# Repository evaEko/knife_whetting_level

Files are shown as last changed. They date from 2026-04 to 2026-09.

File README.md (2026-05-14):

# Knife Level BLUNT

A small digital level for knife sharpening. Measures blade surface inclination in real time, displays the angle, and alerts you when you drift from your target sharpening angle.

 Built on MicroPython running on an nRF52840 microcontroller.

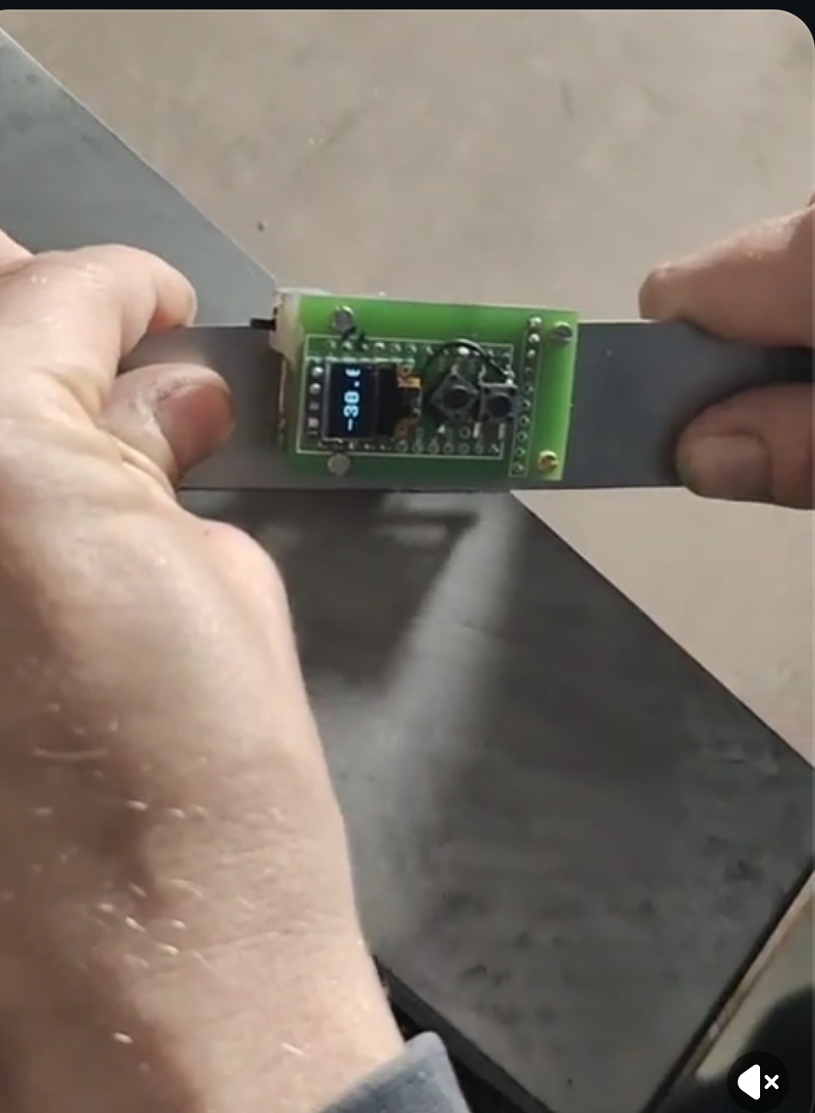
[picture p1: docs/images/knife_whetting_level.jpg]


Here are some vids:
* [demo vid of the sensor responsiveness](https://imgur.com/a/BOzFHaE).
* [demo vid of the Android app](https://i.imgur.com/QXUnDTm.mp4).
* [foolish idea with 2 displays](https://i.imgur.com/3KEsX2l.mp4)

Commercial use and resale are not permitted.

## License

- Software code, documentation, images, and hardware design files: [CC BY-NC 4.0](LICENSE)
- Third-party subcomponents may use their own license where noted (for example, `kicad/nice-nano-kicad/`)

### Third-party notices

- `kicad/nice-nano-kicad/` is a third-party nice!nano symbol/footprint library bundled with this project.
- The bundled library declares `GNU GPLv3` in `kicad/nice-nano-kicad/README.md`; keep that notice and attribution when redistributing those files.

> **Disclaimer:** This project is provided as-is, without warranty of any kind. The author is not liable for any damage, injury, or loss arising from the use, misuse, or inability to use this project or any hardware built from it.

## Getting Started

1. [Assemble the hardware](docs/HOW_TO_HARDWARE.md)
2. [Flash the firmware](docs/HOW_TO_FIRMWARE.md)
3. Optionally install the Android companion app from the `knife_level_android_apk` workflow artifact

If impatient, go over to [Quick Start](docs/QUICK_START.md).

## Known Issues

- **Android app rescan after restart** — if you power-cycle the level, the Android app will not reconnect automatically; open the app and scan again.
- **Lifted detection is experimental** — the feature that detects when the blade leaves the stone is not reliable and may produce false positives or miss lift events; treat alerts that depend on it as best-effort.

## Acknowledgements

Thanks to [jkorte-dev](https://github.com/jkorte-dev) for publishing the nRF52840 SuperMini/Nice!Nano MicroPython board definitions and UF2 builds used as a flashing base.

Development was assisted by [Claude](https://claude.ai) (Anthropic).

## Features

- **Live sharpening angle** — displays current blade surface inclination in real time on the OLED, rounded to nearest 0.5° with one decimal place
- **Rotation-invariant measurement** — the sensor attaches to the blade with a magnet and can spin freely on the blade face; the reading reports the correct blade angle regardless of how the sensor is rotated on the surface
- **Session calibration** — set the current surface as zero from the on-device settings menu or the Android app
- **Angle setting** — set the current angle as the sharpening angle
- **Visual alert** — display inverts when you drift more than the configured threshold from the target angle; both 0° and 180° orientations are treated as equivalent (knife flipped upside-down is the same angle); threshold supports decimal values (e.g. 0.5°)
- **Preset angle profiles** — define named knives and their angles in `angles.csv`; select them on-device with the top button, with optional restore of the last selected preset after reboot
- **Calibration + presets are independent** — calibrate once to set your physical reference point (zero), then switch between knife presets freely; each preset angle is always displayed relative to the calibration, never compounding
- **Bluetooth companion app** — configure display/behavior settings over BLE, calibrate from the phone, manage preset angles with CRUD operations, and back up/restore presets plus app-exposed settings after reflashing

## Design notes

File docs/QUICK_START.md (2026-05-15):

# Quick Start

Below is the simplest possible how-to.

Note: Check out the [TODO](TODO.md) file for useful info on what is probably not working. This repository is still under heavy construction.

## 1. Order the PCB

1. Install [KiCad 10](https://www.kicad.org/download/)
2. Clone this repo or download the kicad files.
2. Open [`kicad/kicad.kicad_sch`](../kicad/kicad.kicad_sch) or one of the available kicad pcb designs: run at least the design rules checker.
3. Generate Gerbers: **File → Fabrication Outputs → Gerbers**
4. Upload to a PCB manufacturer — [AISLER](https://aisler.net) is recommended (EU-based, good quality)

## 2. Buy the Components 

| Part | Notes |
|---|---|
| MCU | **nice!nano v2** (pricier, excellent build quality) or **SuperMini nRF52840** (budget option, same firmware) |
| IMU | BNO085 breakout (GY-BNO08X) |
| Display | SSD1306 0.91" OLED |
| 2× push buttons | Tactile SMD, CK KSC6xxG footprint |
| Latch switch | SPDT or SPST, for B+ power line |
| LiPo battery | 3.7V ~100mAh, smallest that fits under Pro Micro footprint (~20×30mm) |

**Battery life estimate**: with the recommended ~100mAh cell, expect about 4 to 6 hours of continuous use with the display on and BLE enabled.

**Note**: SuperMini clones sometimes need to have a resistor added to allow reading of battery voltage. It is not a showstopper but the displayed battery status will be always 0%.

## 3. Solder

1. **Display** — solder first, it will get blocked by the MCU board.
2. **BNO085 module** — next
3. **MCU** — last; make sure it sits high enough above the PCB for the battery to fit underneath. Consider using machined pin headers (sockets) so you can swap the MCU and battery without desoldering.

## 4. Flash

### 4.1. Install mpremote

**Linux:** `pip install mpremote --break-system-packages`

**macOS:** `pip3 install mpremote`

**Windows:** install [Python from python.org](https://www.python.org/downloads/) (check "Add to PATH"), then `pip install mpremote`

If `mpremote` is not found after installing on Linux/macOS, add it to your PATH:
- Linux: `echo 'export PATH=$HOME/.local/bin:$PATH' >> ~/.bashrc && source ~/.bashrc`
- macOS: `echo 'export PATH=$HOME/.local/bin:$PATH' >> ~/.zshrc && source ~/.zshrc`

### 4.2 Flash MicroPython (one-time)

1. Download the UF2 (from jkorte-dev):
   ```bash
   curl -L -o micropython-NRF52840-supermini-v1.26.1.uf2 \
     https://raw.githubusercontent.com/jkorte-dev/micropython-board-NRF52840/main/firmware/micropython-NRF52840-supermini-v1.26.1.uf2
   ```
2. Connect the MCU with a data USB cable to your computer.
3. Short the **RST** and **GND** pins twice in quick succession — the board mounts as a drive called `NICENANO`
4. Copy the firmware to the bootloader drive:

   **Linux:** `cp micropython-NRF52840-supermini-v1.26.1.uf2 /run/media/$USER/NICENANO/`

   **macOS:** `cp micropython-NRF52840-supermini-v1.26.1.uf2 /Volumes/NICENANO/`

   **Windows:** drag and drop the `.uf2` file onto the `NICENANO` drive in Explorer.

   The drive unmounts automatically.

### 4.3 Flash the firmware

1. Go to the [latest workflow run](https://github.com/evaEko/knife_whetting_level/actions/workflows/build.yml) and download the `knife_level_firmware` artifact. Extract the zip.
2. Go to the extracted folder.
2. Edit `src/angles.csv` or `src/config.txt` before flashing. See [HOW_TO_FIRMWARE.md](HOW_TO_FIRMWARE.md) for details.
5. Run from the folder with extract firmware:

```bash
python flash.py
```

Select your port from the menu when prompted. The script will flash all files and reset the board.

### Android app (optional)

Go to the same [workflow run page](https://github.com/evaEko/knife_whetting_level/actions/workflows/build.yml) and download the `knife_level_android_apk` artifact.

1. Extract the artifact zip on your Android device or computer
2. Copy `app-debug.apk` to your phone if needed
3. Open the APK on the phone and allow installation from unknown sources if Android asks
4. Install the app

**Compatibility**

- Android only
- The app connects directly to the device over BLE; no account, pairing, or cloud service is involved

**Known issues**

- If the MCU is not in measurement mode, the app may stay connected but live angle updates pause until the MCU returns to measuring
- BLE reconnect behavior can vary by phone vendor and Android version; if discovery fails after a disconnect, wait a moment and try again
- The app is distributed as an APK artifact, not through Google Play, so Android may show the standard warning about installing from unknown sources

## 5. Use

**Power on** — battery percentage shows for 1.5 s, then the live pitch angle appears.

### Step 1 — Calibrate

Calibration records the full 3D orientation of the sensor placed flat on the stone. This is the zero reference — all angle readings are relative to the stone surface regardless of how the sensor is mounted or rotated.

Do this at the start of every session, after you have positioned your stone. Redo it whenever the stone moves.

1. Place the device flat on your stone.
2. Short-press the low button to open **Settings**.
3. On **Calibration**, short-press the low button.
4. Short-press the low button again — after a settle delay the reading is saved and the device returns to measurement

The display now shows angles relative to your stone surface.

### Step 2 — Set an angle (optional)

> You can sharpen using the live angle display without setting any target. Setting an angle adds deviation detection with alert: the display inverts when you drift more than the configured deviation threshold (configurable), giving you a visual alert.

Short-press the top button to open the preset menu. Cycle through options with the top button, confirm with the low button.

**To use a preset knife angle** — cycle to the knife name and press low.

**To set a custom angle** - cycle to **Custom** and press low.

**To clear the target** — cycle to **Clear** in the preset menu and press low.

## 6. Charging

> **Important (known limitation):** while charging over USB, the latch power switch must be in the ON position. If the latch switch is OFF, the battery will not charge.

With the recommended ~100mAh battery, a full charge is usually enough for one sharpening session. 

## 8. Reflashing

When you want to update the firmware:

1. Connect to computer.
2. **Short-press both buttons at the same time** — the display shows "Ready to flash..."
   - **Note:** once flash mode is active, the only way out is to reset (short RST to GND) or power off/on.
3. If you are flashing from the downloaded firmware package, run `python flash.py`
4. If you are flashing from this repository checkout, run `python build_flash.py`

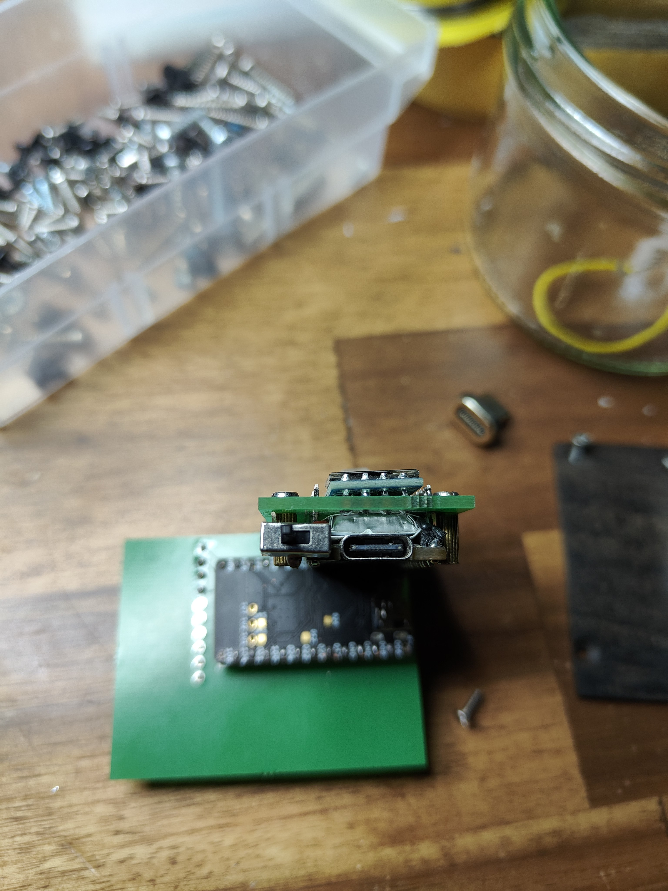
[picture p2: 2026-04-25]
docs/images/pcb_ready/ready_front.jpg

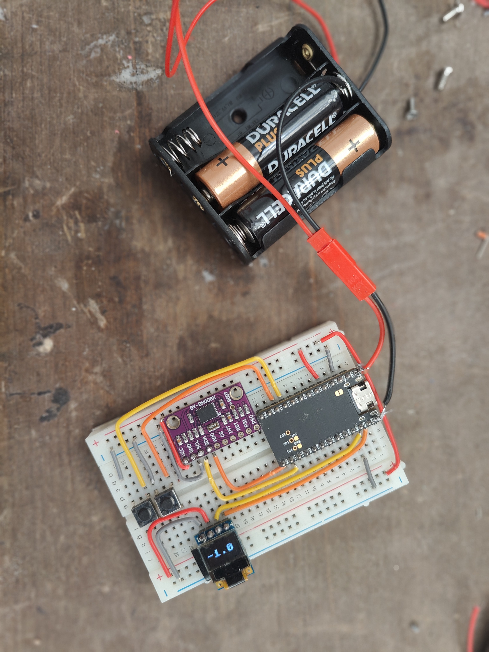
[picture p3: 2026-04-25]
docs/images/breadboard/breadboard_bat.jpg

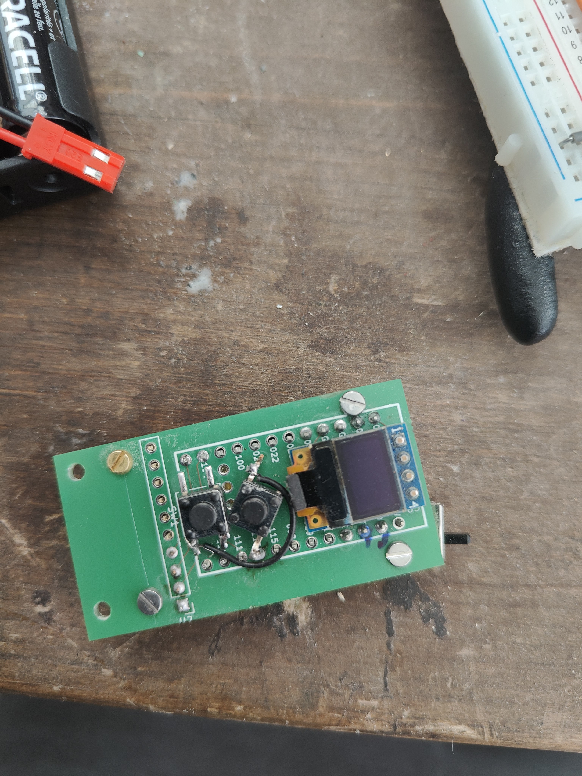
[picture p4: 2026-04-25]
docs/images/pcb_ready/ready_top.jpg

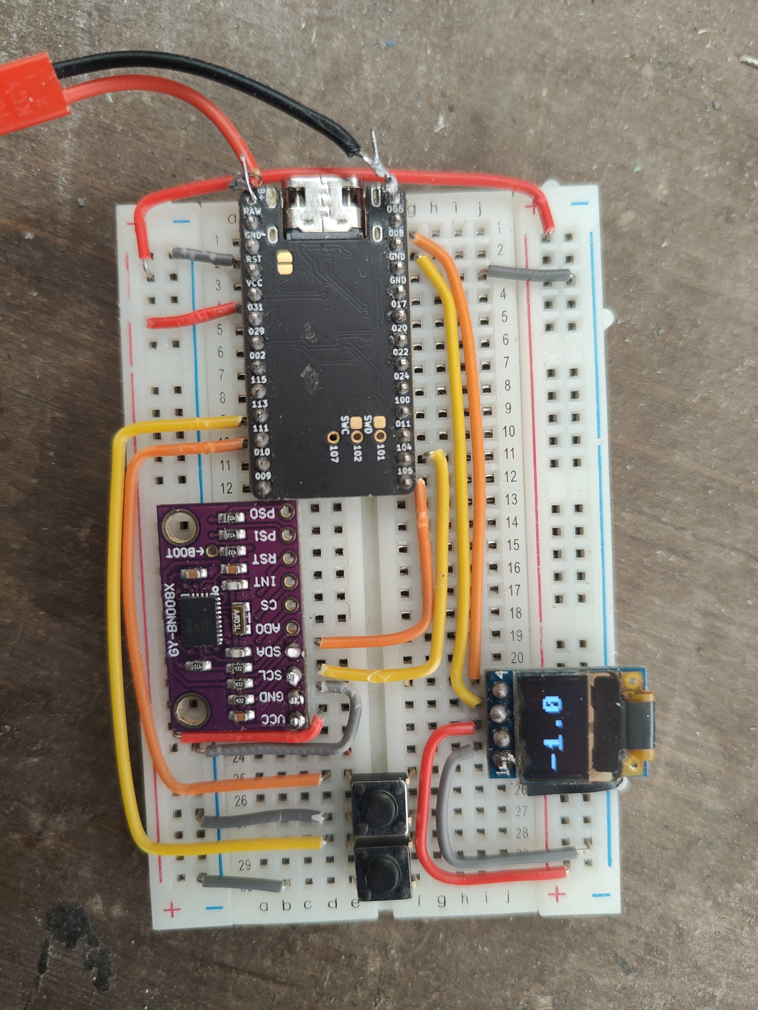
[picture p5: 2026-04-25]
docs/images/breadboard/breadboard.jpg

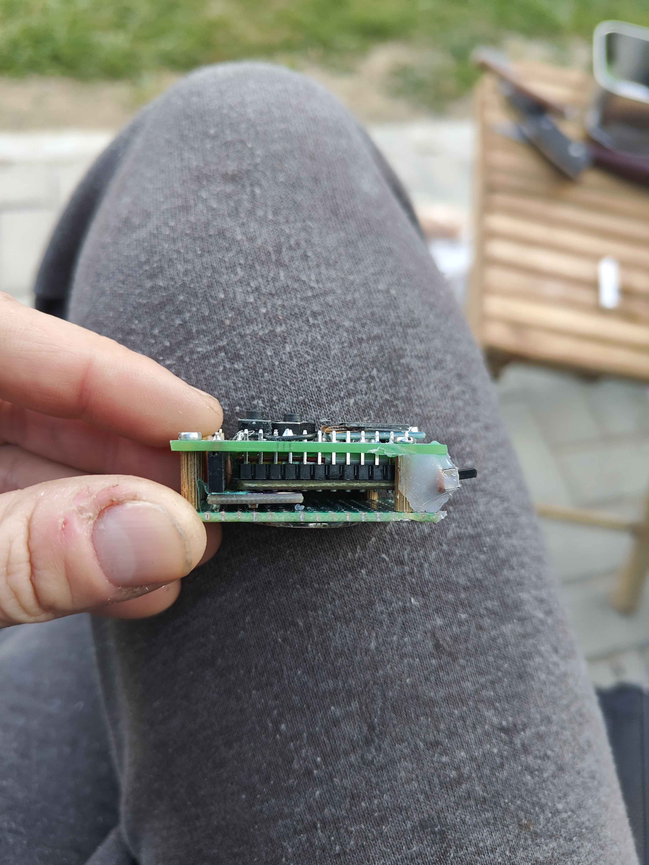
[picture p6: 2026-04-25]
docs/images/pcb_ready/ready_side.jpg

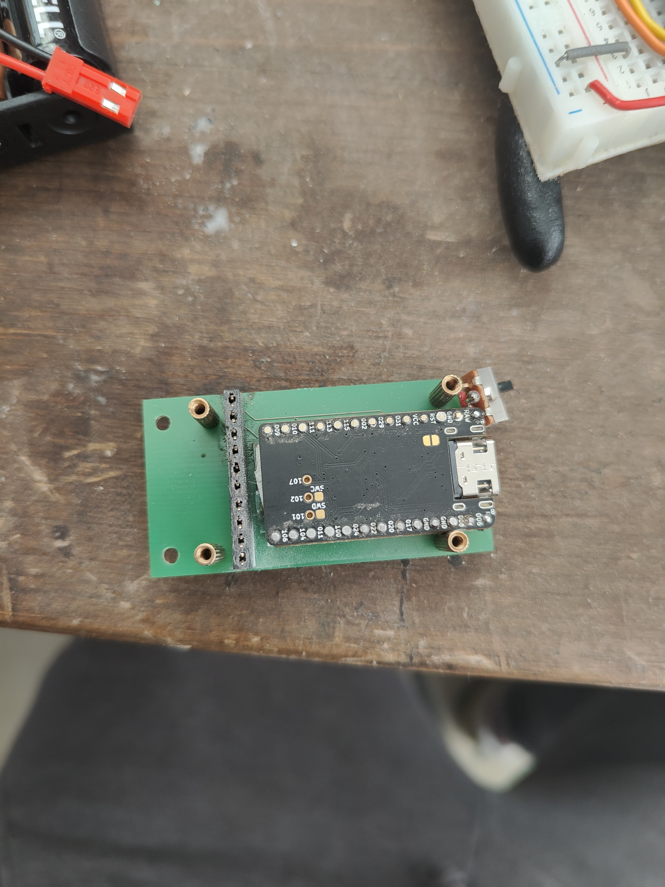
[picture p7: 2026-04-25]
docs/images/pcb_ready/ready_bottom.jpg

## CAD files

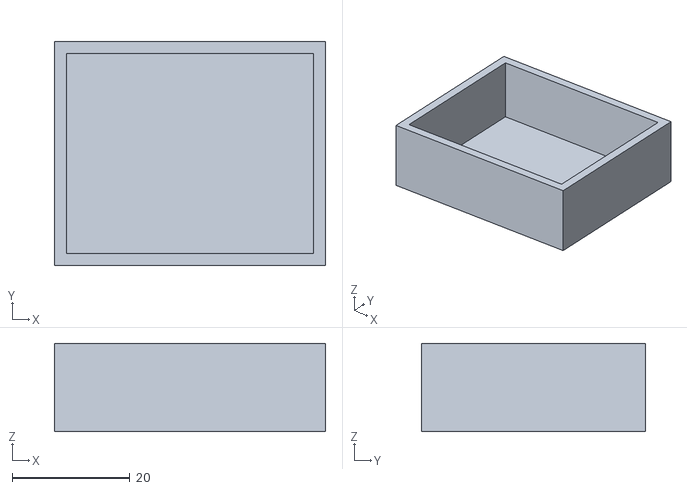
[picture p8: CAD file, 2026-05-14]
case/device_housing.stl
46.0 x 38.0 x 15.0

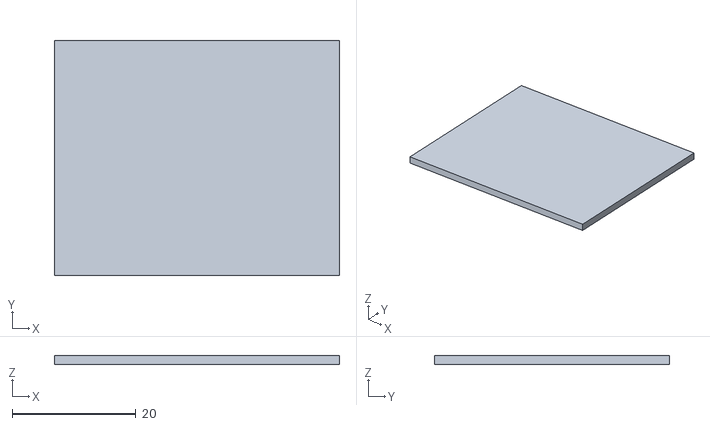
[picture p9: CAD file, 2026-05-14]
case/device_lid.stl
46.0 x 38.0 x 1.50

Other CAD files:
case/case.blend

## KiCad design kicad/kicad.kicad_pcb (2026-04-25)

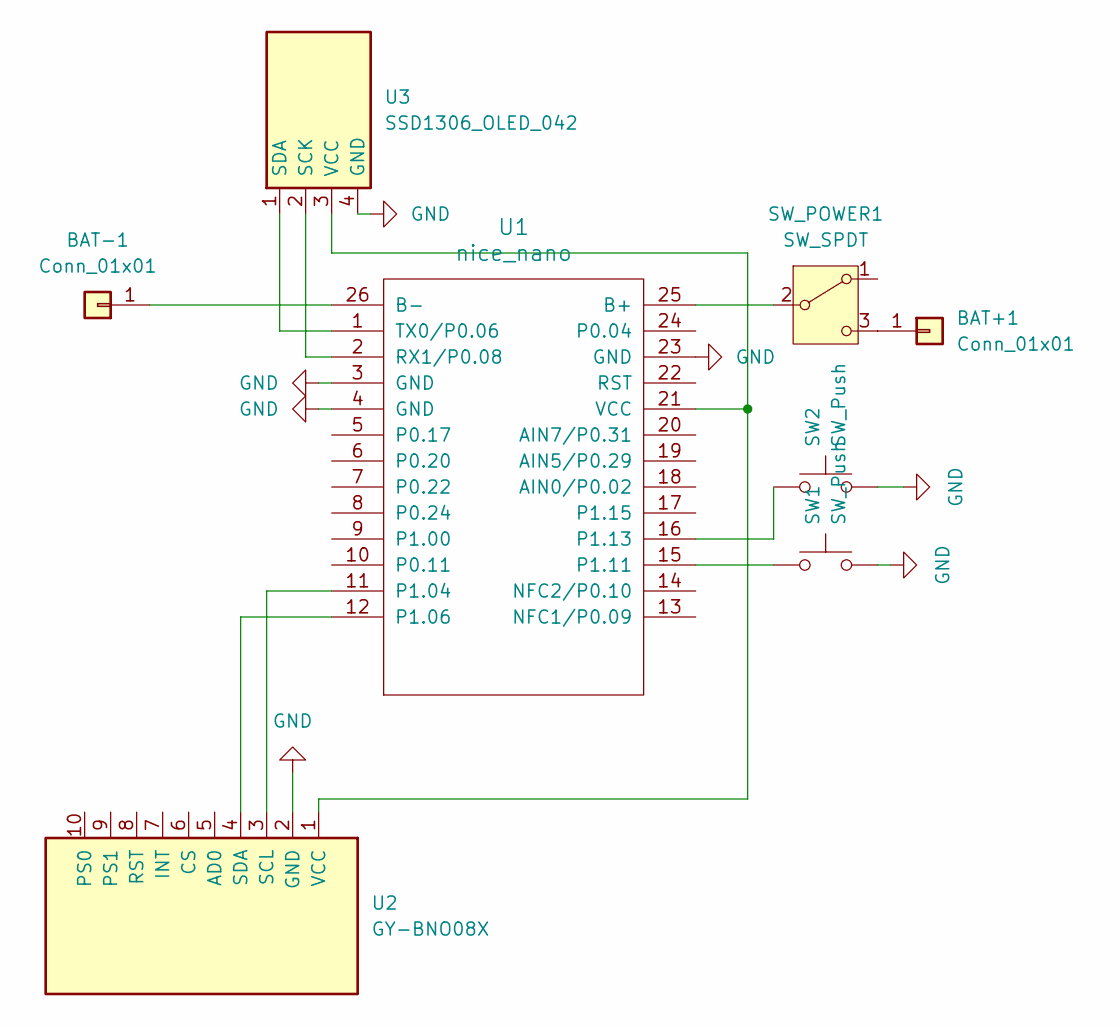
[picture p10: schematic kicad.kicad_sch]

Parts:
BAT+1: Conn_01x01; SolderWire-0.1sqmm_1x01_D0.4mm_OD1mm
BAT-1: Conn_01x01; SolderWire-0.1sqmm_1x01_D0.4mm_OD1mm
SW1, SW2: SW_Push; SW_Push_1P1T_NO_CK_KSC6xxG
SW_POWER1: SW_SPDT; SW_SPDT_Shouhan_MSK12C02
U1: nice_nano; nice_nano_with_bat_pins
U2: GY-BNO08X; PinHeader_1x10_P2.54mm_Vertical
U3: SSD1306_OLED_042; PinHeader_1x04_P2.54mm_Vertical

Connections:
GND: SW1.2, SW2.2, U1.3 (GND), U1.4 (GND), U1.23 (GND), U2.2 (GND), U3.4 (GND)
unnamed: BAT+1.1, SW_POWER1.3 (C)
unnamed: BAT-1.1, U1.26 (B-)
unnamed: SW_POWER1.2 (B), U1.25 (B+)
unnamed: U1.11 (P1.04), U2.3 (SCL)
unnamed: U1.12 (P1.06), U2.4 (SDA)
unnamed: SW1.1, U1.15 (P1.11)
unnamed: SW2.1, U1.16 (P1.13)
unnamed: U1.2 (RX1/P0.08), U3.2 (SCK)
unnamed: U1.1 (TX0/P0.06), U3.1 (SDA)
unnamed: U1.21 (VCC), U2.1 (VCC), U3.3 (VCC)

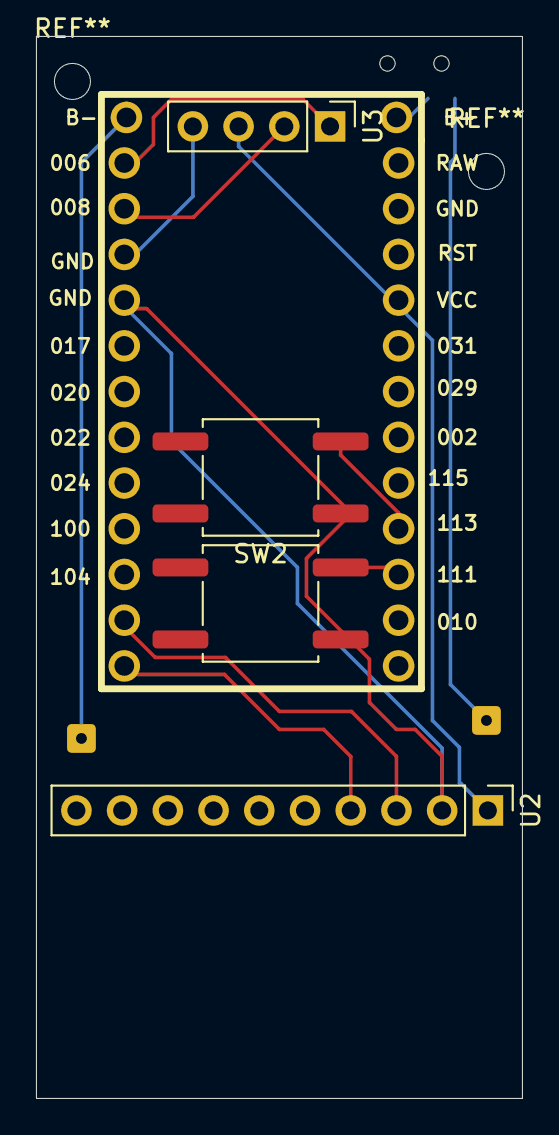
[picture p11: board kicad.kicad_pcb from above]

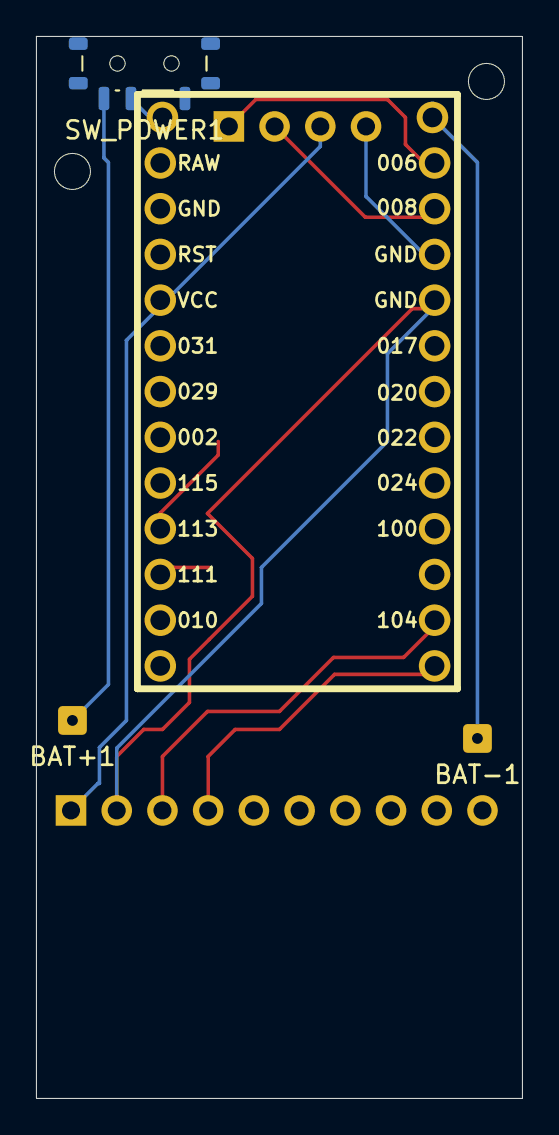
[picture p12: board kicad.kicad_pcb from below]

Board: 2 copper layers, 27.0 x 59.0 mm, 8 parts (3 on the bottom side), 11 nets.

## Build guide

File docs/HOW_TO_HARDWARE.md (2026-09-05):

# Hardware Assembly

The KiCad schematic is in [`kicad/kicad.kicad_sch`](../kicad/kicad.kicad_sch). Open it in KiCad 10 to view the full schematic and generate gerbers for PCB fabrication. Have it fabricated. 

It is possible to do this on perfboard: it is a good idea to breadboard it first and plan the perfboard version, use both sides (TODO: documentation of perfboard options).

If you have the PCB, solder in this order: display first, then the BNO085 module, then the MCU. Leave enough clearance under the MCU for the battery. Connect the battery wires to B+ and B- directly on the MCU board.

Consider socketing the MCU using mill-max or machined pin headers instead of soldering it directly. This lets you swap or replace the board without desoldering.

Refer to the images on [breadboarding](images/breadboard/)
and on [PCB assembly](images/pcb_assembly/)

After assembly, [flash the firmware](HOW_TO_FIRMWARE.md)

## Bill of Materials

| Component | Part | Notes |
|---|---|---|
| Microcontroller | **nice!nano** or nRF52840 pro-micro compatible board | nRF52840-based, chosen for built-in LiPo charging — no separate charging module needed |
| IMU | BNO085 | I2C, addr `0x4B` |
| Display | 0.42" OLED (SSD1306) | I2C, 72×40 px, addr `0x3C` |
| Two push buttons  | Tactile push button | SMD, e.g. CK KSC6xxG footprint |
| Battery | LiPo 3.7V 100mAh | Smallest single-cell LiPo that fits under the Pro Micro footprint (e.g. 20×30mm) |
| PCB| Custom PCB (see kicad folder) | The PCB makes everything simpler, however, you can perfboard it: you will need to use both sides: plan ahead. |

## Note on MCU Board

The following boards have been tested and confirmed working:

- **nice!nano v1.0** — works
- **nice!nano v2.0** — works (recommended; has the most reliable charging circuit)
- **SuperMini nRF52840** — works; cheaper alternative, pin-compatible with nice!nano

All three use the nRF52840 and support the same MicroPython firmware. Choose any of them — the firmware runs identically on all.

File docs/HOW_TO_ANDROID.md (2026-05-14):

# HOW TO: Blunt Android App

## What is the Blunt Android App?
The Blunt Android app is a companion application for the Knife Level device. It allows you to connect to your level via Bluetooth, view measurements, set target angles, and customize alerts. The app is not required for using the Knife Level — it is provided purely for convenience and enhanced user experience.

### Settings available from the app

The settings screen has two tabs: **Application** (stored on the phone) and **Level** (sent to the device over BLE).

#### Application tab

**Lifted**
- **Enable** — detect when the blade leaves the stone and pause deviation alerts
- **Velocity threshold (°/s)** — minimum angular speed that triggers a lift event (3–30°/s); lower = more sensitive
- **Debounce (ms)** — how long to wait after the last movement before returning to on-stone state (200–4000 ms); higher = fewer false detections when holding the blade in the air

**Measurement Data**
- **Angle Format** — `2d` (two decimals), `1d` (one decimal), `0.5` (nearest 0.5°)
- **Target Name** — show the preset name (e.g. Gyuto) above the live angle
- **Target Angle** — show the target angle value below the live reading
- **Deviation Range** — show the allowed angle range (e.g. 13.0°–17.0°) based on target and threshold
- **Delta** — show the signed difference between the live angle and the target (e.g. Δ+1.2°)

**Visual Alert**
- **Direction Arrows** — show ↑↓ arrows indicating which way to correct the blade; the active arrow turns the alert colour when outside the threshold
- **Arrow Size** — Small / Medium / Large / XL (shown when Direction Arrows is on)
- **Background Color** — change the background colour when outside the deviation threshold
- **Angle too high / too low colour** — pick from Red, Orange, Pink, Teal, Blue (shown when Background Color is on)

**Sound Alert**
- **On angle too high** — play a tone when the blade is above target + threshold; tone pitch and optional custom audio file are configurable
- **On angle too low** — play a tone when the blade is below target − threshold; tone pitch and optional custom audio file are configurable
- **On target** — play a custom audio file (looped) when the blade is within the target range; resumes from where it was interrupted
  - **Continue on lifted** — keep the on-target audio playing when the blade is lifted off the stone

**Custom Angle**
- **Measurement delay (s)** — countdown before the live angle is captured as a custom target (1–15 s); gives time to position the blade

#### Level tab

These settings are written to the device over BLE. Press **Apply** to send.

- **Deviation Threshold (°)** — how far from the target angle before the display inverts (0.0°–4.0°)
- **Capture delay (s)** — settle time before the surface normal is sampled during calibration (1–30 s)

## Installation
You have two options to install the app on your Android phone:

### Option 1: Download APK from Workflow
1. Go to the GitHub repository's Actions tab.
2. Find the latest successful build workflow run.
3. Download the APK artifact to your phone or computer.
4. Transfer the APK to your phone if needed.
5. On your phone, open the APK file and follow the prompts to install. You may need to allow installation from unknown sources.

### Option 2: Build and Install Yourself
1. Install Android Studio (https://developer.android.com/studio) and required SDKs.
2. Clone the repository to your computer.
3. Open the `App` project in Android Studio.
4. Connect your Android phone via USB and enable USB debugging.
5. Click "Run" in Android Studio to build and install the app directly to your device.

## Uploading and Running the App
- After installation, locate the Blunt app icon on your phone and open it.
- Grant all requested permissions (Bluetooth, Location) for proper operation.
- The app will scan for your Knife Level device. Select it to connect.

## Troubleshooting
- **I cannot see my level during scanning:**
  - Make sure BLE is enabled on your Knife Level device.
  - Check if the device appears in your phone's Bluetooth device list. If not, turn the level off and on again.
- **I can't see details about my target angle:**
  - Ensure you have selected a preset or set a custom angle in the app.
- **I don't want some of the alerts:**
  - Go to the app's settings and customize or disable alerts as desired.

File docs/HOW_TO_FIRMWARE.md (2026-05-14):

# How To

## Setup

### Install Python

Make sure Python 3 is installed:

```bash
python --version
```

Python 3.10+ is recommended.

### Install git

**Linux (Debian/Ubuntu):**
```bash
sudo apt install git
```

**Linux (Fedora):**
```bash
sudo dnf install git
```

**macOS:**
```bash
brew install git
```

**Windows:** Download from [git-scm.com](https://git-scm.com/download/win) and run the installer.

### Flash MicroPython (one-time)

MicroPython must be flashed to the board before deploying any code. Download the UF2 from the upstream board-definition repository.

1. **Enter bootloader** — double-tap the reset button on the board. A drive called `NICENANO` will mount.
2. **Download UF2**:
   ```bash
   curl -L -o micropython-NRF52840-supermini-v1.26.1.uf2 \
     https://raw.githubusercontent.com/jkorte-dev/micropython-board-NRF52840/main/firmware/micropython-NRF52840-supermini-v1.26.1.uf2
   ```
3. **Flash**:

   **Linux:**
   ```bash
   cp micropython-NRF52840-supermini-v1.26.1.uf2 /run/media/$USER/NICENANO/
   ```
   **macOS:**
   ```bash
   cp micropython-NRF52840-supermini-v1.26.1.uf2 /Volumes/NICENANO/
   ```
   **Windows:** drag and drop the `.uf2` file onto the `NICENANO` drive in Explorer.

   The board reboots automatically when the copy completes.
4. **Verify** — the `NICENANO` drive disappears and a serial port appears (`/dev/ttyACM0` on Linux, `/dev/tty.usbmodem*` on macOS, `COM*` on Windows).

### Downloading release artifacts

If you do not want to build from the repository manually, open the [Build artifacts workflow](https://github.com/evaEko/knife_whetting_level/actions/workflows/build.yml) and download:

- `knife_level_firmware` for the packaged firmware bundle
- `knife_level_android_apk` for the Android companion app APK

### Install mpremote

**Linux:**
```bash
pip install mpremote --break-system-packages
```
If `mpremote` is not found after installing, add `~/.local/bin` to your PATH:
```bash
echo 'export PATH=$HOME/.local/bin:$PATH' >> ~/.bashrc && source ~/.bashrc
```

**macOS:**
```bash
pip3 install mpremote
```
If `mpremote` is not found, add it to your PATH:
```bash
echo 'export PATH=$HOME/.local/bin:$PATH' >> ~/.zshrc && source ~/.zshrc
```

**Windows:** install [Python from python.org](https://www.python.org/downloads/) (check "Add to PATH" during install), then:
```
pip install mpremote
```

---

## Flashing

### Prepare sources

Clone the repository:

```bash
git clone https://github.com/evaEko/knife_whetting_level.git
cd knife_whetting_level
```

Edit [`src/config.txt`](../src/config.txt) to set your pin assignments, deviation threshold, and capture delay before flashing. The file is a simple `key=value` text file — each line is self-explanatory.

You can also edit [`src/angles.csv`](../src/angles.csv) before flashing if you want to ship a default preset list in the firmware image.

### Connecting the MCU

Plug in the device and find the assigned serial port:

**Linux:** run `dmesg -w` before plugging in and look for a line like:
```
cdc_acm 3-2:1.0: ttyACM0: USB ACM device
```
The port will be `/dev/ttyACM0` or similar.

**macOS:** run `ls /dev/tty.usbmodem*` after plugging in. The port will be something like `/dev/tty.usbmodem1101`.

**Windows:** open Device Manager → Ports (COM & LPT) — the device will appear as `USB Serial Device (COM3)` or similar.

### Getting the device ready to flash

mpremote needs the device to be at the MicroPython REPL prompt before it can transfer files. There are two ways to get there:

Short-press both buttons simultaneously

Press both buttons at the same time (short press). The display will show "Ready to flash..." and the device drops to REPL.

Note: once flash mode is active, the only way out is to reset (short RST to GND) or power-cycle the device.

### Flash automatically

Run from the `knife_level_python` directory:

```bash
python build_flash.py
```

You can also pass the serial port explicitly, for example:

```bash
python build_flash.py /dev/ttyACM0
```

The script auto-discovers all files under `src/` (excluding `src/tools/`) and flashes them in one go. `angles.csv` is also flashed automatically.

### REPL access

```bash
mpremote connect /dev/ttyACM0 repl
```

Hit **Ctrl+C** to interrupt `main.py` and get the `>>>` prompt.

## Runtime controls

- Short-press low: open settings menu (`Calibration`, `BLE`, `Deviation`, `Exit`)
- Short-press top (when calibrated): open preset-angle selection menu
- Short-press top (when uncalibrated): go directly to calibration capture
- Short-press both buttons: enter flash mode

### Settings menu

| Item | Behaviour |
|---|---|
| Calibration | Capture stone surface normal; top=cancel, low=capture |
| BLE | Toggle BLE on/off (top), back to menu (low) |
| Deviation | Adjust deviation threshold; top=+0.1°, long-top=+0.5°, low=save, long-low=cancel |
| Exit | Return to measurement |

### Preset-angle selection menu

Cycle through presets with top, confirm with low. Special items at the end:

| Item | Behaviour |
|---|---|
| Custom | Capture the current blade angle as target; top=cancel, low=capture |
| Clear | Unset the current target angle and return to measurement |
| Exit | Return to measurement without changing target |

### Android companion app

Install it from the `knife_level_android_apk` workflow artifact. Refer to [Android app how-to](HOW_TO_ANDROID.md)

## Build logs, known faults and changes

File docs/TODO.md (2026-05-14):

# TODO

# Case

work in progress

# Firmware

* implement correct detection of battery connected when on usb cable
* refactor ble protocol and related
* fix battery status reading

# Known Issues

- Battery readings can be erratic.
- Occasionally, the Android app cannot detect the level; if this happens, turn the level device off and on again, enable bluetooth and in your Android app rescan.

## GitHub

## PCB

- tidy up: currently multiple versions: the default one, one with sensor on the side, one with sensor on the size and with a larger display (driver needed), 

## Angle Format Setting

## Measurement Improvements

### On-Stone Detection *(needs improvement)*
Basic implementation in place: pitch-based threshold (12°) with 800 ms debounce
on return. Known limitations:
- Threshold is a fixed degree value, not tied to actual blade/stone geometry
- Does not distinguish "blade lifted" from "blade at wrong angle on stone"
- Needs real-world tuning across different sharpening angles and users

## Tests *(from plan — desktop, no hardware)*

- [ ] `test_calibrate_state.py`
- [ ] `test_deviation_state.py`
- [ ] `test_storage_service.py`
- [ ] `test_config_service.py`
- [ ] `test_bno085_parse.py` — parse_reports returns correct accel/gyro tuples

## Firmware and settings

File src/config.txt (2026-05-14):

sda_imu=38
scl_imu=36
sda_oled=6
sck_oled=8
i2c_id_imu=0
i2c_id_oled=1
bno085_addr=75
oled_addr=60
btn_low=43
btn_top=45
deviation_threshold=2.0
capture_delay_sec=5
ble_enabled=0

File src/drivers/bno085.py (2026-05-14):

import struct
import time

# SHTP channels
_CHAN_CONTROL = 2
_CHAN_REPORTS = 3

# SH-2 report IDs
_GAME_ROTATION_VECTOR = 0x08
_GYRO_CALIBRATED      = 0x02
_SET_FEATURE_CMD      = 0xFD
_BASE_TIMESTAMP       = 0xFB
_COMMAND_REQUEST      = 0xF2

# SH-2 command IDs
_CMD_ME_CALIBRATE = 0x07

_Q14        = 16384.0
_Q9         = 512.0
_MAX_PACKET = 128


class BNO085:
    """Static driver — knows the BNO085 SHTP protocol. No state."""

    @staticmethod
    def read_packet(i2c, addr):
        """Read one SHTP packet. Returns (channel, payload) or None."""
        try:
            header = i2c.readfrom(addr, 4)
        except OSError:
            return None
        length = (header[1] & 0x7F) << 8 | header[0]
        if length < 4 or length > 32768:
            return None
        read_len = min(length, _MAX_PACKET)
        try:
            data = i2c.readfrom(addr, read_len)
        except OSError:
            return None
        return (data[2], data[4:read_len])

    @staticmethod
    def send_packet(i2c, addr, seq, channel, payload):
        """Send one SHTP packet. Returns updated seq array."""
        length = len(payload) + 4
        header = bytes([
            length & 0xFF,
            (length >> 8) & 0x7F,
            channel,
            seq[channel],
        ])
        seq[channel] = (seq[channel] + 1) & 0xFF
        i2c.writeto(addr, header + bytes(payload))
        return seq

    @staticmethod
    def _enable_report(i2c, addr, seq, report_id, interval_ms):
        interval_us = interval_ms * 1000
        cmd = bytearray(17)
        cmd[0] = _SET_FEATURE_CMD
        cmd[1] = report_id
        struct.pack_into('<I', cmd, 5, interval_us)
        seq = BNO085.send_packet(i2c, addr, seq, _CHAN_CONTROL, cmd)
        time.sleep_ms(50)
        for _ in range(5):
            BNO085.read_packet(i2c, addr)
            time.sleep_ms(10)
        return seq

    @staticmethod
    def enable_rotation_vector(i2c, addr, seq, interval_ms=10):
        """Enable game rotation vector report."""
        return BNO085._enable_report(i2c, addr, seq, _GAME_ROTATION_VECTOR, interval_ms)

    @staticmethod
    def enable_gyro(i2c, addr, seq, interval_ms=10):
        """Enable calibrated gyroscope report."""
        return BNO085._enable_report(i2c, addr, seq, _GYRO_CALIBRATED, interval_ms)

    @staticmethod
    def configure_calibration(i2c, addr, seq, accel=True, gyro=True, mag=False):
        """Configure dynamic calibration per sensor."""
        cmd = bytearray(12)
        cmd[0] = _COMMAND_REQUEST
        cmd[1] = 0
        cmd[2] = _CMD_ME_CALIBRATE
        cmd[3] = 0
        cmd[4] = 1 if accel else 0
        cmd[5] = 1 if gyro  else 0
        cmd[6] = 1 if mag   else 0
        seq = BNO085.send_packet(i2c, addr, seq, _CHAN_CONTROL, cmd)
        time.sleep_ms(50)
        for _ in range(5):
            BNO085.read_packet(i2c, addr)
            time.sleep_ms(10)
        return seq

    @staticmethod
    def parse_reports(payload):
        """Parse all sensor reports in payload.
        Returns dict with 'quat' (w,x,y,z) and/or 'gyro' (x,y,z rad/s), or None."""
        result = {}
        i = 0
        while i < len(payload):
            report_id = payload[i]
            if report_id == _BASE_TIMESTAMP and i + 5 <= len(payload):
                i += 5
            elif report_id == _GAME_ROTATION_VECTOR and i + 12 <= len(payload):
                qi = struct.unpack_from('<h', payload, i + 4)[0] / _Q14
                qj = struct.unpack_from('<h', payload, i + 6)[0] / _Q14
                qk = struct.unpack_from('<h', payload, i + 8)[0] / _Q14
                qr = struct.unpack_from('<h', payload, i + 10)[0] / _Q14
                result['quat'] = (qr, qi, qj, qk)
                i += 12
            elif report_id == _GYRO_CALIBRATED and i + 10 <= len(payload):
                gx = struct.unpack_from('<h', payload, i + 4)[0] / _Q9
                gy = struct.unpack_from('<h', payload, i + 6)[0] / _Q9
                gz = struct.unpack_from('<h', payload, i + 8)[0] / _Q9
                result['gyro'] = (gx, gy, gz)
                i += 10
            else:
                break
        return result or None


class IMU:
    """Instance — owns i2c connection, seq counters and latest quaternion for one BNO085 chip."""

    def __init__(self, i2c, addr=0x4A, rst=None):
        self.i2c   = i2c
        self.addr  = addr
        self._seq  = [0] * 6
        self._quat = (1.0, 0.0, 0.0, 0.0)  # w, x, y, z
        self._gyro = (0.0, 0.0, 0.0)        # x, y, z rad/s

        if rst is not None:
            rst.value(0)
            time.sleep_ms(10)
            rst.value(1)
            time.sleep_ms(100)

        time.sleep_ms(200)
        for _ in range(10):
            BNO085.read_packet(self.i2c, self.addr)
            time.sleep_ms(10)

        self._seq = BNO085.enable_rotation_vector(self.i2c, self.addr, self._seq)
        self._seq = BNO085.enable_gyro(self.i2c, self.addr, self._seq)

    def update(self):
        """Drain all available packets, update state. Returns True if new rotation data."""
        got_data = False
        for _ in range(20):
            result = BNO085.read_packet(self.i2c, self.addr)
            if result is None:
                break
            channel, payload = result
            if channel == _CHAN_REPORTS and len(payload) >= 1:
                parsed = BNO085.parse_reports(payload)
                if parsed:
                    if 'quat' in parsed:
                        self._quat = parsed['quat']
                        got_data = True
                    if 'gyro' in parsed:
                        self._gyro = parsed['gyro']
        return got_data

    def get_gravity(self):
        """Gravity unit vector derived from quaternion (gx, gy, gz)."""
        w, x, y, z = self._quat
        return (
            2.0 * (w * y - x * z),
            -2.0 * (y * z + x * w),
            2.0 * (x * x + y * y) - 1.0,
        )

    def get_angular_velocity(self):
        """Angular velocity vector (x, y, z) in rad/s."""
        return self._gyro

    def is_spinning(self, threshold_rads=0.5):
        """True if angular speed exceeds threshold (default 0.5 rad/s ≈ 30°/s)."""
        gx, gy, gz = self._gyro
        return (gx*gx + gy*gy + gz*gz) > threshold_rads * threshold_rads

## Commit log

2026-04-21 more or less correct
    [config.py]
2026-04-21 new filter: madgwick
2026-04-21 replace BMI160 with BNO085 (TenStar TS2129Y)
    Use BNO085's onboard sensor fusion (game rotation vector, no mag)
    instead of software Madgwick filter. Removes gyro calibration step,
    MadgwickFilter class, and BMI160 driver.
    [bno085.py, config.py]
2026-04-21 use pitch,accept upside down position
    [kicad.kicad_pcb, kicad.kicad_sch]
2026-04-21 fix on sleep fail
    [bno085.py]
2026-04-21 battery detection for nice nano
2026-04-21 add missing dep files, update readme
    [battery.py, calibration.py]
2026-04-21 update nice nano footprint
2026-04-21 started working on new pcb
    [kicad.kicad_pcb, kicad.kicad_sch]
2026-04-21 add b+ and b- pins
    [kicad.kicad_pcb, kicad.kicad_sch]
2026-04-23 fix b+ and b- traces in pcb
    [kicad.kicad_pcb, kicad.kicad_sch]
2026-04-23 kicad cleanup
    [kicad.kicad_pcb, kicad.kicad_sch]
2026-04-23 add switch to pcb
    [kicad.kicad_pcb, kicad.kicad_sch]
2026-04-24 move 2nd button to 113
    [kicad.kicad_pcb, kicad.kicad_sch]
2026-04-24 refactor state machine: clean main, ctx module, init/measure/calibrate/power states
2026-04-24 minors, docs
    [angles.csv]
2026-04-25 preset the angle relative to calibration
2026-04-25 document the calibration and preset separation
2026-04-25 scaffold for board leveling
    [angles.csv]
2026-04-25 scaffold for board levelling
2026-04-25 add board levelling
2026-04-25 fix board levelling
2026-04-26 clear cal on board level
2026-04-26 add custom preset angle
    [angles.csv]
2026-04-27 display message when turn on required for charging
2026-04-27 improve charging bypass
2026-04-27 improve battery check
2026-04-27 fix varios minors, format
    [battery.py, config.py, display.py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]
2026-04-27 delay board levelling
2026-04-27 suport roll and pitch config
    [angles.csv]
2026-04-27 add mini pcb version(as printed by aisler as v2.0)
    [kicad_sensor_on_side.kicad_pcb]
2026-04-27 android: implement calibration
2026-04-28 fix setting angle from android app
    [ble.py, measure.py]
2026-04-28 tweaking buttons
2026-04-30 get all settings to gear settings
2026-04-30 change level setting via ble without reboot)
    [ble.py, measure.py]
2026-05-01 add back button behavior on preset
2026-05-02 remove pitch and roll
2026-05-02 remove roll and pitch from android
2026-05-04 refactor device god object: split of ble
2026-05-05 implement sampling on board levelling
2026-05-05 calibrate on an even surface
2026-05-06 improve battery voltage reading
2026-05-06 start case
    [Untitled.blend, case.blend, device_housing.stl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]
2026-05-06 remove bogus blender
    [Untitled.blend]
2026-05-09 improve board levelling
2026-05-12 Refactor firmware: src_ref with DI, adaptive smoothing, preset angles
    - Rebuild firmware in src_ref/ with dependency injection via Container
    - Switch to Game Rotation Vector with adaptive EMA (frozen/active alpha)
    matching src/ smoothing behaviour
    - Accelerometer + gyroscope driver supporting both reports
    - Two-step stone calibration (n_stone + target angle); board levelling removed
    - Preset angle store backed by angles.csv with single-item selector UI
    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
    [config.txt]
2026-05-12 add missing files
    [angles.csv]
2026-05-12 refactoring:add battery status
2026-05-12 refactoring: fix button action on ble
2026-05-12 refactoring: fix minors
    [config.txt]
2026-05-12 refactoring: src_ref -> src
    [angles.csv, config.txt]
2026-05-13 various fixes
    [kicad_sensor_on_side.kicad_pcb]
2026-05-13 add pcb for big display
    [kicad_sensor_on_side_big_display.kicad_pcb]
2026-05-14 firmware: spin check with gyro
2026-05-14 misc minor fixes
    [config.txt, kicad_sensor_on_side_big_display.kicad_pcb]
2026-05-15 thicker traces for battery in pcb
    [kicad_sensor_on_side.kicad_pcb]
